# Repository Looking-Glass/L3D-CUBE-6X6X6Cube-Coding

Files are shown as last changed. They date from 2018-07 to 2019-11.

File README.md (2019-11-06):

# HOW TO PROGRAM THE 6X6X6 CUBE WITH ARDUINO

Step 1.     Followed the instructions in the Arduino_STM wiki: https://github.com/rogerclarkmelbourne/Arduino_STM32/wiki/Installation

Step 2. 	  Unzip <L3D_CubePixel.zip> and <beta-cube-library.zip> and put these two libraries under arduino library folder  ..\..\arduino-1.6.5-r5-windows\arduino-1.6.5-r5\libraries

Step 3.        Restart Arduino IDE, then select Maple (Rev3) for programming.
**If you can not find Maple(Rev3) on the board menu, replace the Arduino_STM32 folder with this one https://github.com/rogerclarkmelbourne/Arduino_STM32

**Enclosed two Demos x6CubeDemo.zip and x6CubeMusicPack.zip for reference, enjoy!

The Schematic and PCB source files can be open with Eagle PCB.

Enclosed some screenshot for Arauino IDE setting up for reference as well

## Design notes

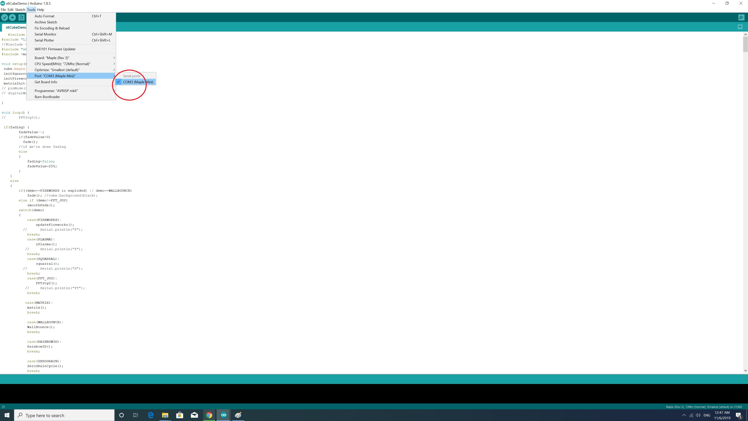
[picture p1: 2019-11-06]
select Maple for Port.jpg

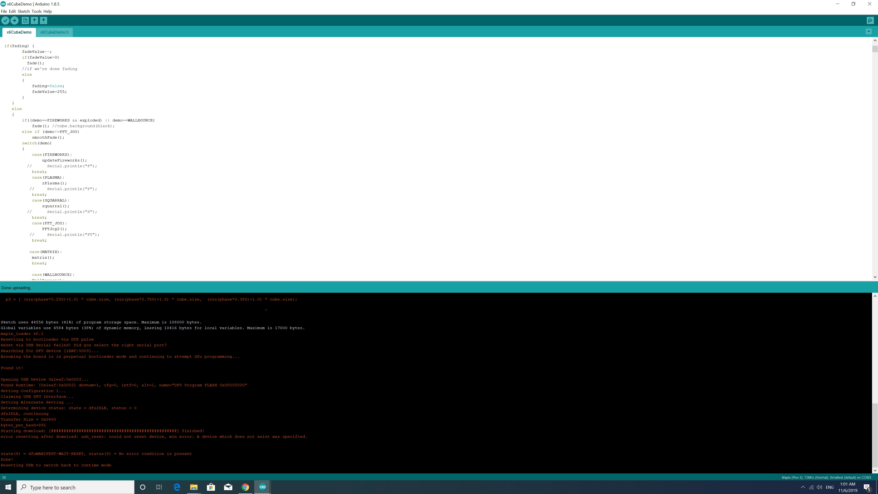
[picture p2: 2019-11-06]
done uploading.jpg

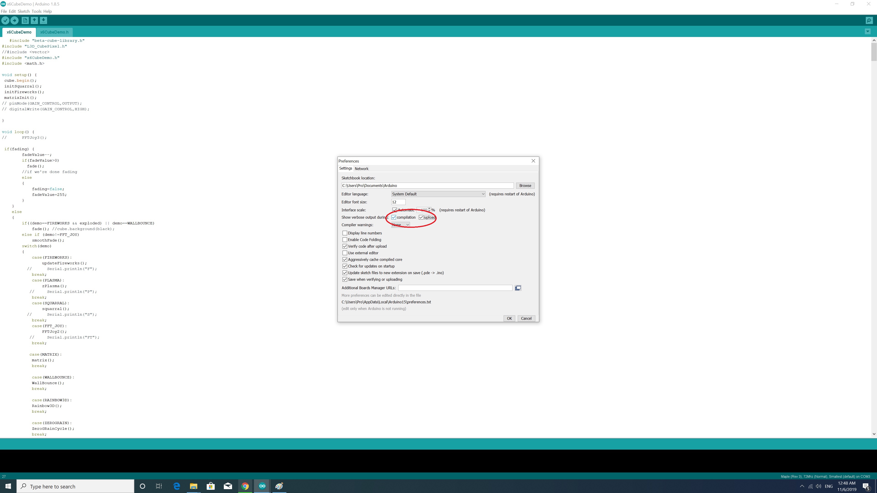
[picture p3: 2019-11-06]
enable verbose output during compilation and upload.jpg

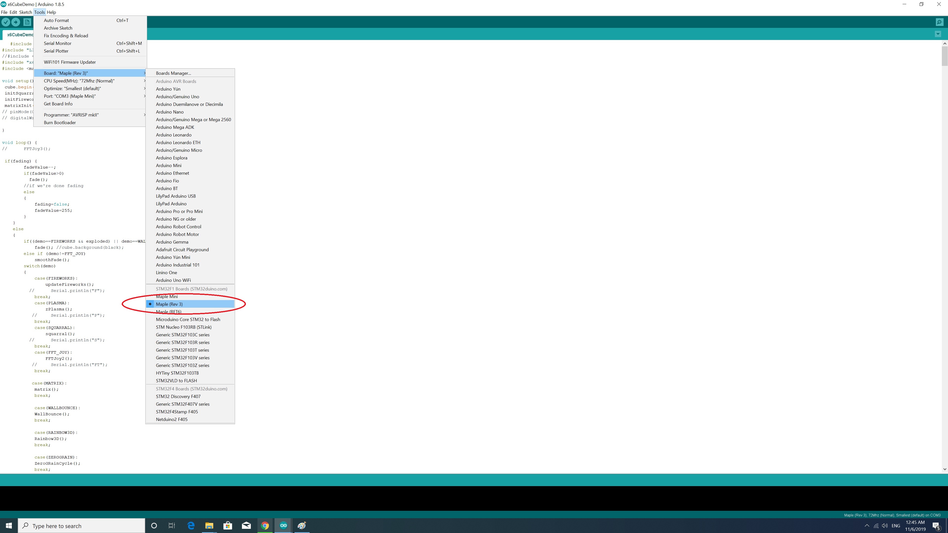
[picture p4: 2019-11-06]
select Maple (Rev3) for Board.jpg

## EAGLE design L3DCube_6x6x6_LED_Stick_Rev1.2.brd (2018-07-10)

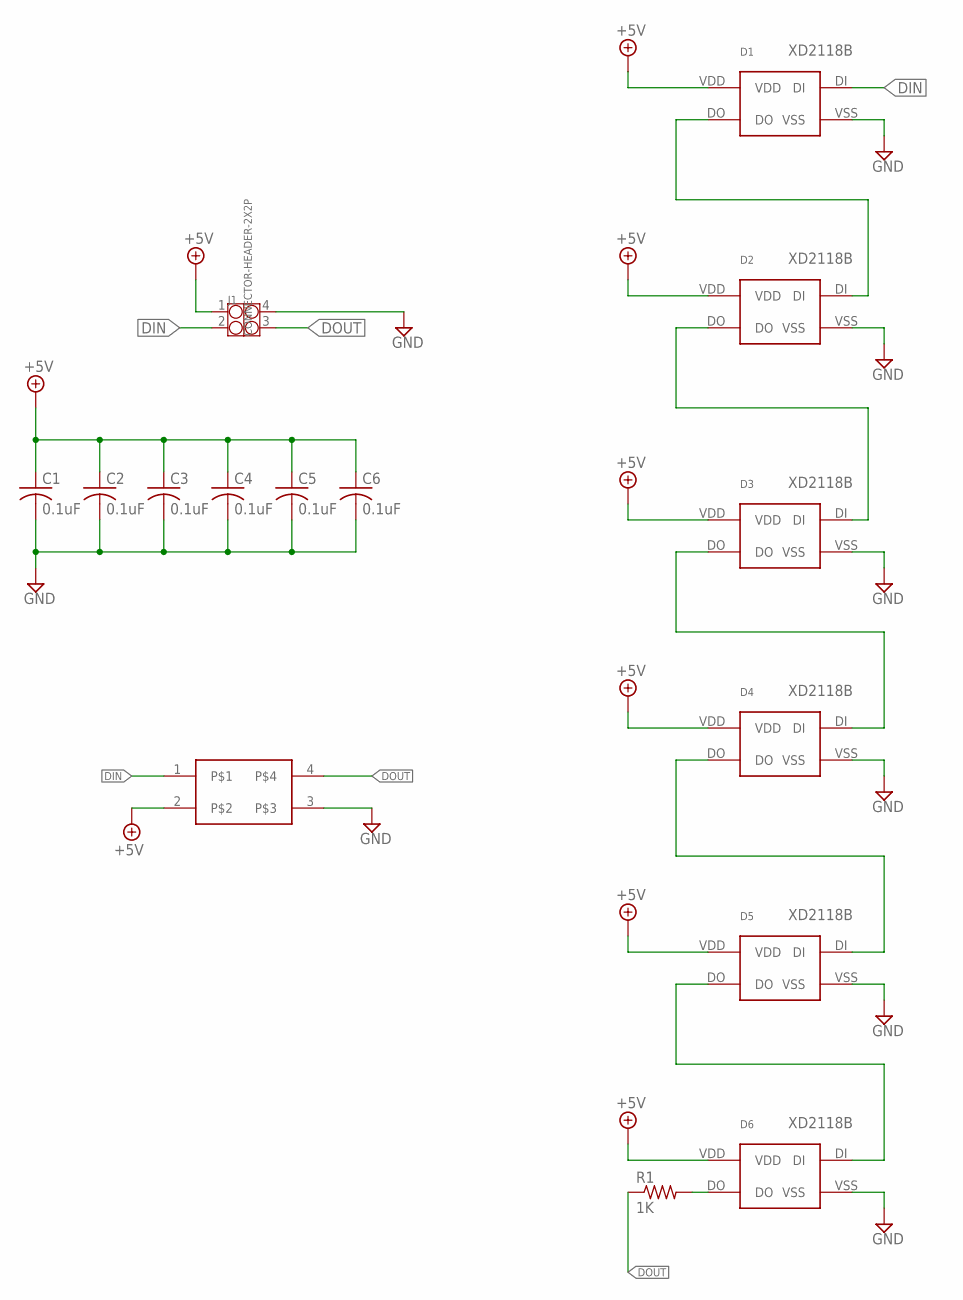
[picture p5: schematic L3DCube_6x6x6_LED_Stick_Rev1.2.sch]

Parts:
C1, C2, C3, C4, C5, C6: 0.1uF; C0402
D1, D2, D3, D4, D5, D6: XD2118B; WS2812B
J1: CONNECTOR-HEADER-2X2P; 2X2P-2.54
R1: 1K; R0402
U$1: TESTPAD-2X2-2.54; 2X2P-2.54-TESTPAD

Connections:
+5V: C1.1, C2.1, C3.1, C4.1, C5.1, C6.1, D1.VDD, D2.VDD, D3.VDD, D4.VDD, D5.VDD, D6.VDD, J1.1, U$1.2
DIN: D1.DI, J1.2, U$1.1
DOUT: J1.3, R1.1, U$1.4
GND: C1.2, C2.2, C3.2, C4.2, C5.2, C6.2, D1.VSS, D2.VSS, D3.VSS, D4.VSS, D5.VSS, D6.VSS, J1.4, U$1.3
unnamed: D1.DO, D2.DI
unnamed: D2.DO, D3.DI
unnamed: D3.DO, D4.DI
unnamed: D4.DO, D5.DI
unnamed: D5.DO, D6.DI
unnamed: D6.DO, R1.2

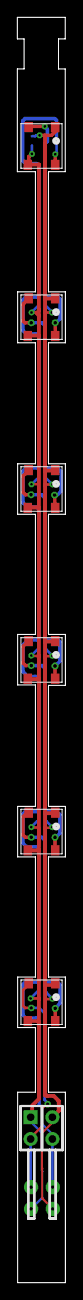
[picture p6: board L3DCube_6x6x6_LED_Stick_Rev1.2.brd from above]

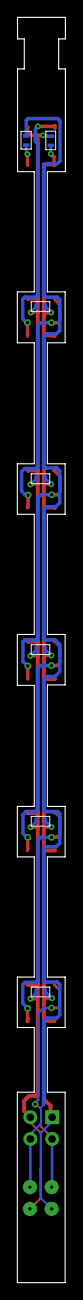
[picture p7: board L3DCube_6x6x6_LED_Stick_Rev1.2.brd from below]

Board: 2 copper layers, 5.6 x 147.6 mm, 15 parts (7 on the bottom side), 10 nets.

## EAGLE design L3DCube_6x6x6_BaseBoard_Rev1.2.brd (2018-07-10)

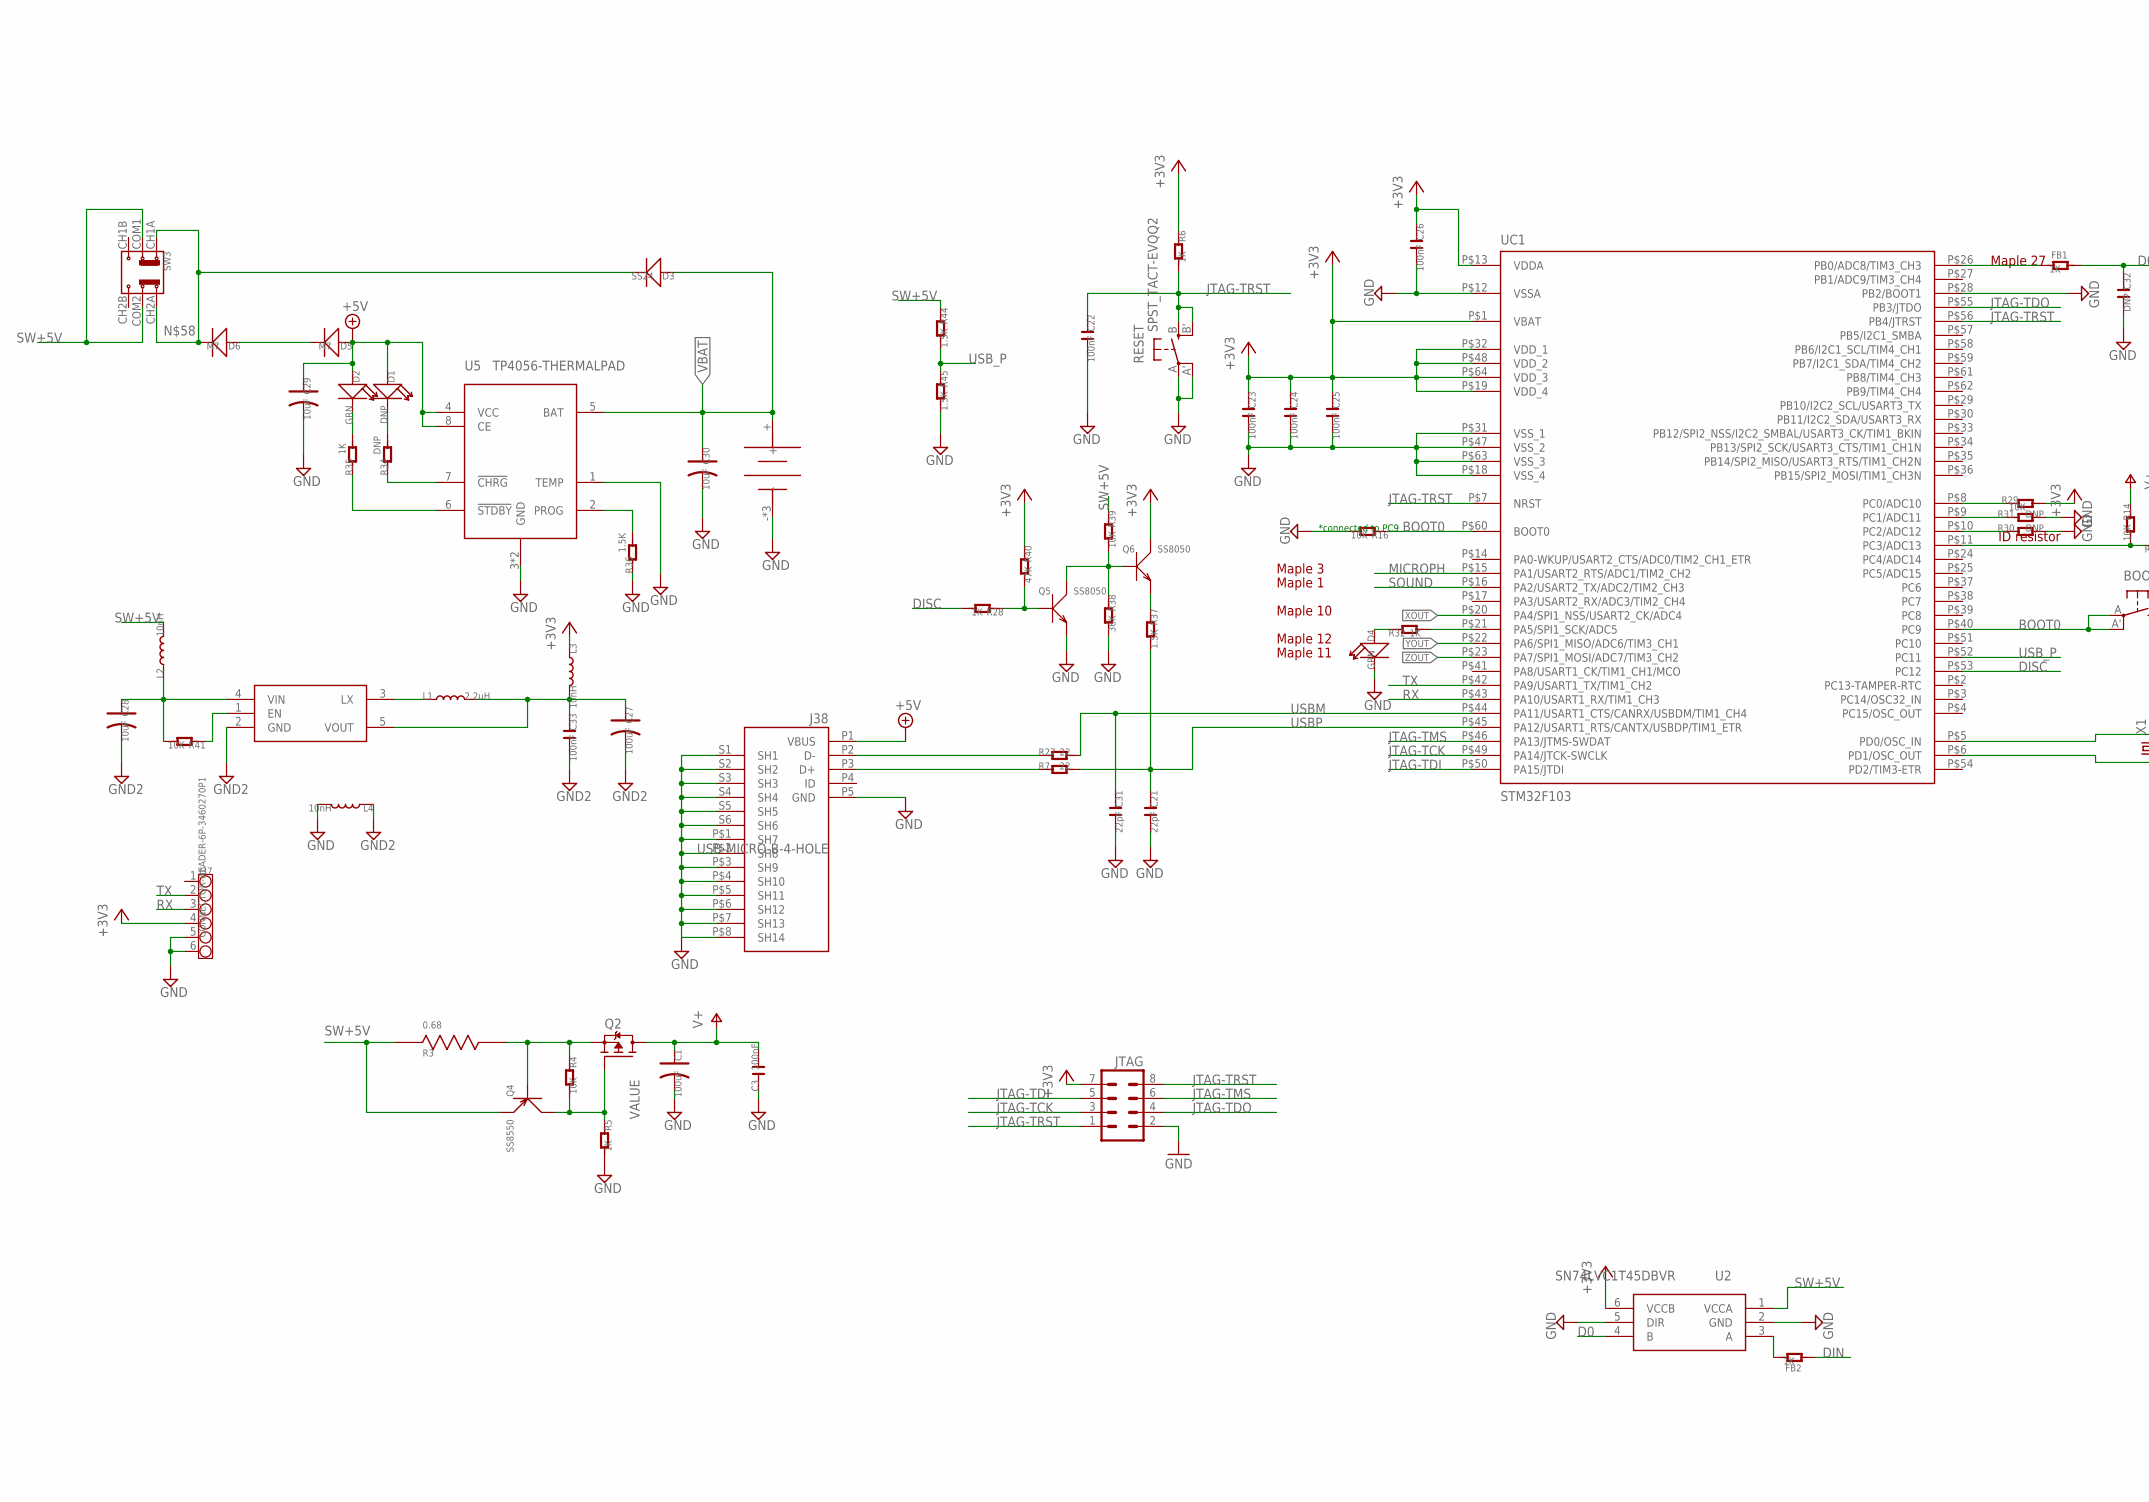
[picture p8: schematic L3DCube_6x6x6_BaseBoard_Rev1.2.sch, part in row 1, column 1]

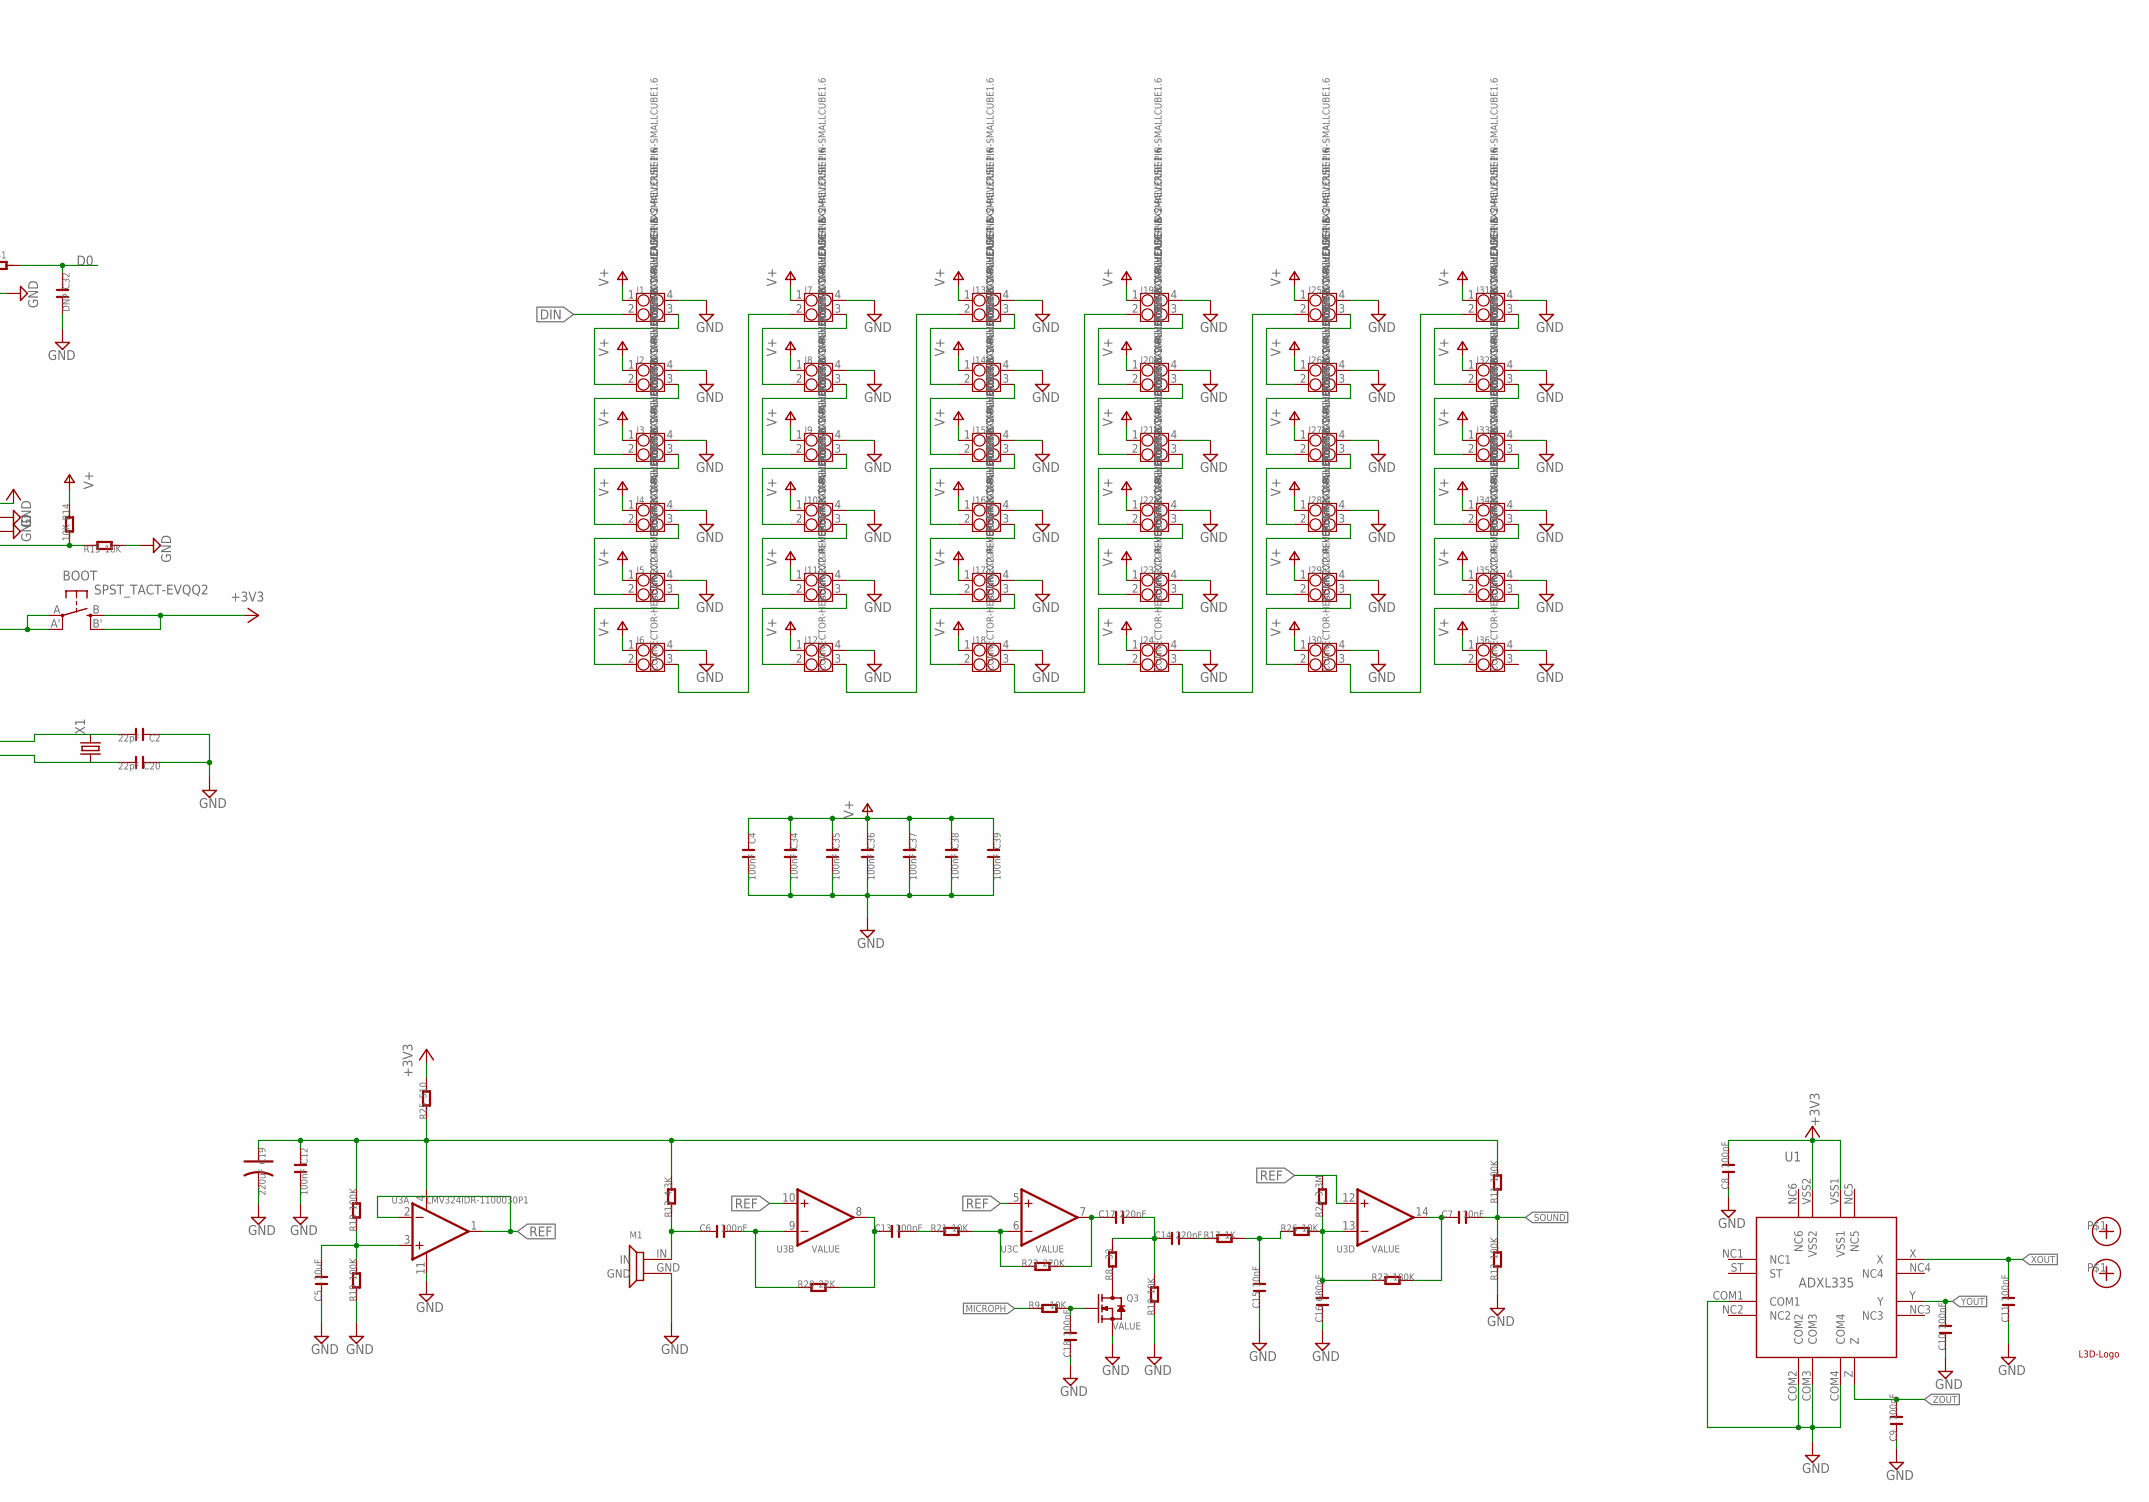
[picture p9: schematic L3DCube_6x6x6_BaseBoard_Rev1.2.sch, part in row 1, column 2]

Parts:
B1: BATTERY; 2P-SMD-2.0-90D
BOOT: SPST_TACT-EVQQ2; EVQ-Q2
C1, C27: 100uF; AVX-B
C2, C20, C21, C31: 22pF; C0603
C3, C4, C6, C8, C9, C10, C11, C12, C13, C18, C22, C23, C24, C25, C26, C33, C34, C35, C36, C37, C38, C39: 100nF; C0603
C5: 10uF; C0603
C7, C15: 10nF; C0603
C14, C17: 220nF; C0603
C16: 680pF; C0603
C19: 220uF; AVX-B
C28, C29, C30: 10uF; AVX-A
C32: DNP; C0603
D1: DNP; LED0603
D2, D4: GRN; LED0603
D3: SS24; SMB
D5, D6: M7; DO-214AC
FB1, FB2: 1K; R0603
J1, J2, J3, J4, J5, J6, J7, J8, J9, J10, J11, J12, J13, J14, J15, J16, J17, J18, J19, J20, J21, J22, J23, J24, J25, J26, J27, J28, J29, J30, J31, J32, J33, J34, J35, J36: CONNECTOR-HEADER-2X2-REVERSE-PIN-SMALLCUBE1.6; 2X2P-2.54-6X6X6-CUBE-TH
J37: CONNECTOR-HEADER-6P-3460270P1; 1X6P-2.54-8.5-BLACK-FEMALE
J38: USB-MICRO-B-4-HOLE; CON2_USB_MICRO_B_AT
JTAG: MA04-2
L1: 2.2uH; L0420
L2, L3, L4: 10nH; L0603
M1: MICROPHONE
Q2: FDD6637; TO252
Q3: 2N7002; SOT23
Q4: SS8550; SOT23
Q5, Q6: SS8050; SOT23
R3: 0.68; RESISTOR-3W-20MM
R4, R9, R10, R14, R15, R16, R21, R26, R29, R39: 10K; R0603
R5, R6, R17, R28, R32, R35: 1K; R0603
R7, R27: 22; R0603
R8: 33; R0603
R11, R12, R18, R19: 100K; R0603
R13: 4.3K; R0603
R20: 22K; R0603
R22: 220K; R0603
R23: 180K; R0603
R24: 3.3M; R0603
R25: 510; R0603
R30, R31, R34: DNP; R0603
R36, R37, R44, R45: 1.5K; R0603
R38: 36K; R0603
R40: 47K; R0603
R41: 10K; R0402
RESET: SPST_TACT-EVQQ2; EVQ-Q2
SW3: SWITCH-22D02
U1: ADXL335
U2: SN74LVC1T45DBVR; SOT23-6
U3: LMV324IDR-1100030P1; SOIC14
U5: TP4056-THERMALPAD; SOIC8-PAD
U11: R8008-33; SOT23-5
U$1: L3D-LOGOL3DCUBE-LOGO-0.8X2.5; L3DCUBE-LOGO-0.8X2.5
U$2, U$3: FIDUCIAL-MARK
UC1: STM32F103; TQFP-10X10-64
X1: CRYSTALSM49; SM49

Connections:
+3V3: BOOT.B (S), BOOT.B' (S1), C8.2, C23.1, C24.1, C25.1, C26.1, J37.4, JTAG.7, L3.1, Q6.3 (C), R6.1, R25.2, R29.1, R40.1, U1.VSS1, U1.VSS2, U2.6 (VCCB), UC1.P$1 (VBAT), UC1.P$13 (VDDA), UC1.P$19 (VDD_4), UC1.P$32 (VDD_1), UC1.P$48 (VDD_2), UC1.P$64 (VDD_3)
+5V: C29.+ (1), D1.+, D2.+, D5.1 (+), J38.P1 (VBUS), U5.4 (VCC), U5.8 (CE)
BOOT0: BOOT.A, BOOT.A' (P1), R16.1, UC1.P$40 (PC9), UC1.P$60 (BOOT0)
D0: C32.1, FB1.1, U2.4 (B)
DIN: FB2.1, J1.2
DISC: R28.2, UC1.P$53 (PC12)
ENABLE: R41.1, U11.1 (EN)
GND: B1.3 (-), B1.4 (-), B1.-, C1.- (2), C2.1, C3.1, C4.2, C5.1, C8.1, C9.1, C10.1, C11.1, C12.2, C15.1, C16.1, C18.1, C19.- (2), C20.1, C21.2, C22.2, C23.2, C24.2, C25.2, C26.2, C29.- (2), C30.- (2), C31.2, C32.2, C34.2, C35.2, C36.2, C37.2, C38.2, C39.2, D4.-, J1.4, J2.4, J3.4, J4.4, J5.4, J6.4, J7.4, J8.4, J9.4, J10.4, J11.4, J12.4, J13.4, J14.4, J15.4, J16.4, J17.4, J18.4, J19.4, J20.4, J21.4, J22.4, J23.4, J24.4, J25.4, J26.4, J27.4, J28.4, J29.4, J30.4, J31.4, J32.4, J33.4, J34.4, J35.4, J36.4, J37.5, J37.6, J38.P5 (GND), J38.P$1 (SH7), J38.P$2 (SH8), J38.P$3 (SH9), J38.P$4 (SH10), J38.P$5 (SH11), J38.P$6 (SH12), J38.P$7 (SH13), J38.P$8 (SH14), J38.S1 (SH1), J38.S2 (SH2), J38.S3 (SH3), J38.S4 (SH4), J38.S5 (SH5), J38.S6 (SH6), JTAG.2, L4.2, M1.GND, Q3.2 (S), Q5.2 (E), R5.2, R10.1, R12.1, R15.2, R16.2, R19.1, R30.2, R31.2, R36.1, R38.2, R45.2, RESET.A, RESET.A' (P1), U1.COM1, U1.COM2, U1.COM3, U1.COM4, U2.2 (GND), U2.5 (DIR), U3.11 (V-), U5.1 (TEMP), U5.3 (GND), U5.GND1 (GND), UC1.P$12 (VSSA), UC1.P$18 (VSS_4), UC1.P$28 (PB2/BOOT1), UC1.P$31 (VSS_1), UC1.P$47 (VSS_2), UC1.P$63 (VSS_3)
GND2: C27.- (2), C28.- (2), C33.2, L4.1, U11.2 (GND)
JTAG-TCK: JTAG.3, UC1.P$49 (PA14/JTCK-SWCLK)
JTAG-TDI: JTAG.5, UC1.P$50 (PA15/JTDI)
JTAG-TDO: JTAG.4, UC1.P$55 (PB3/JTDO)
JTAG-TMS: JTAG.6, UC1.P$46 (PA13/JTMS-SWDAT)
JTAG-TRST: C22.1, JTAG.1, JTAG.8, R6.2, RESET.B (S), RESET.B' (S1), UC1.P$7 (NRST), UC1.P$56 (PB4/JTRST)
LED1: D4.+, R32.1
MICROPH: R9.1, UC1.P$15 (PA1/USART2_RTS/ADC1/TIM2_CH2)
unnamed: J1.3, J2.2
unnamed: J2.3, J3.2
unnamed: J3.3, J4.2
unnamed: J4.3, J5.2
unnamed: J5.3, J6.2
unnamed: J7.3, J8.2
unnamed: J8.3, J9.2
unnamed: J9.3, J10.2
unnamed: J10.3, J11.2
unnamed: J11.3, J12.2
unnamed: J13.3, J14.2
unnamed: J14.3, J15.2
unnamed: J15.3, J16.2
unnamed: J16.3, J17.2
unnamed: J17.3, J18.2
unnamed: J19.3, J20.2
unnamed: J20.3, J21.2
unnamed: J21.3, J22.2
unnamed: J22.3, J23.2
unnamed: J23.3, J24.2
unnamed: J25.3, J26.2
unnamed: J26.3, J27.2
unnamed: J27.3, J28.2
unnamed: J28.3, J29.2
unnamed: J29.3, J30.2
unnamed: J31.3, J32.2
unnamed: J32.3, J33.2
unnamed: J33.3, J34.2
unnamed: J34.3, J35.2
unnamed: J35.3, J36.2
unnamed: J6.3, J7.2
unnamed: C18.2, Q3.1 (G), R9.2
unnamed: J12.3, J13.2
unnamed: J18.3, J19.2
unnamed: J24.3, J25.2
unnamed: J30.3, J31.2
unnamed: C2.2, UC1.P$5 (PD0/OSC_IN), X1.2
unnamed: C20.2, UC1.P$6 (PD1/OSC_OUT), X1.1
unnamed: R14.2, R15.1, UC1.P$11 (PC3/ADC13)
unnamed: J38.P2 (D-), R27.1
unnamed: L1.1, U11.3 (LX)
unnamed: D1.-, R34.2
unnamed: R32.2, UC1.P$21 (PA5/SPI1_SCK/ADC5)
unnamed: FB1.2, UC1.P$26 (PB0/ADC8/TIM3_CH3)
unnamed: R29.2, UC1.P$8 (PC0/ADC10)
unnamed: D2.-, R35.2
unnamed: R34.1, U5.7 (!CHRG)
unnamed: R35.1, U5.6 (!STDBY)
unnamed: R36.2, U5.2 (PROG)
unnamed: R30.1, UC1.P$10 (PC2/ADC12)
unnamed: Q6.2 (E), R37.1
unnamed: C28.+ (1), L2.1, R41.2, U11.4 (VIN)
unnamed: R31.1, UC1.P$9 (PC1/ADC11)
unnamed: J38.P3 (D+), R7.1
unnamed: C27.+ (1), C33.1, L1.2, L3.2, U11.5 (VOUT)
unnamed: FB2.2, U2.3 (A)
unnamed: D3.-, D6.2 (-), SW3.CH1A, SW3.CH2A
unnamed: D5.2 (-), D6.1 (+)
unnamed: Q2.2 (S), Q4.1 (B), R3.2, R4.1
unnamed: Q3.3 (D), R8.1
unnamed: Q2.1 (G), Q4.3 (C), R4.2, R5.1
unnamed: C14.2, R17.1
unnamed: C15.2, R17.2, R26.1
unnamed: C16.2, R23.1, R24.1, R26.2, U3.13 (IN-)
unnamed: Q5.3 (C), Q6.1 (B), R38.1, R39.2
unnamed: C6.1, M1.IN, R13.1
unnamed: Q5.1 (B), R28.1, R40.2
unnamed: C5.2, R18.1, R19.2, U3.3 (IN+)
unnamed: C6.2, R20.1, U3.9 (IN-)
unnamed: C13.1, R20.2, U3.8 (OUT)
unnamed: C13.2, R21.1
unnamed: R21.2, R22.1, U3.6 (IN-)
unnamed: C14.1, C17.2, R8.2, R10.2
unnamed: C12.1, C19.+ (1), R11.2, R13.2, R18.2, R25.1, U3.4 (V+)
unnamed: C7.1, R23.2, U3.14 (OUT)
unnamed: C17.1, R22.2, U3.7 (OUT)
REF: R24.2, U3.1 (OUT), U3.2 (IN-), U3.5 (IN+), U3.10 (IN+), U3.12 (IN+)
RX: J37.3, UC1.P$43 (PA10/USART1_RX/TIM1_CH3)
SOUND: C7.2, R11.1, R12.2, UC1.P$16 (PA2/USART2_TX/ADC2/TIM2_CH3)
SW+5V: L2.2, Q4.2 (E), R3.1, R39.1, R44.1, SW3.COM1, SW3.COM2, U2.1 (VCCA)
TX: J37.2, UC1.P$42 (PA9/USART1_TX/TIM1_CH2)
USBM: C31.1, R27.2, UC1.P$44 (PA11/USART1_CTS/CANRX/USBDM/TIM1_CH4)
USBP: C21.1, R7.2, R37.2, UC1.P$45 (PA12/USART1_RTS/CANTX/USBDP/TIM1_ETR)
USB_P: R44.2, R45.1, UC1.P$52 (PC11)
V+: C1.+ (1), C3.2, C4.1, C34.1, C35.1, C36.1, C37.1, C38.1, C39.1, J1.1, J2.1, J3.1, J4.1, J5.1, J6.1, J7.1, J8.1, J9.1, J10.1, J11.1, J12.1, J13.1, J14.1, J15.1, J16.1, J17.1, J18.1, J19.1, J20.1, J21.1, J22.1, J23.1, J24.1, J25.1, J26.1, J27.1, J28.1, J29.1, J30.1, J31.1, J32.1, J33.1, J34.1, J35.1, J36.1, Q2.3 (D), R14.1
VBAT: B1.+, C30.+ (1), D3.+, U5.5 (BAT)
XOUT: C11.2, U1.X, UC1.P$20 (PA4/SPI1_NSS/USART2_CK/ADC4)
YOUT: C10.2, U1.Y, UC1.P$22 (PA6/SPI1_MISO/ADC6/TIM3_CH1)
ZOUT: C9.2, U1.Z, UC1.P$23 (PA7/SPI1_MOSI/ADC7/TIM3_CH2)

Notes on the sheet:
*connected to PC9
ID resistor
Maple 27
Maple 3
Maple 1
Maple 10
Maple 12
Maple 11

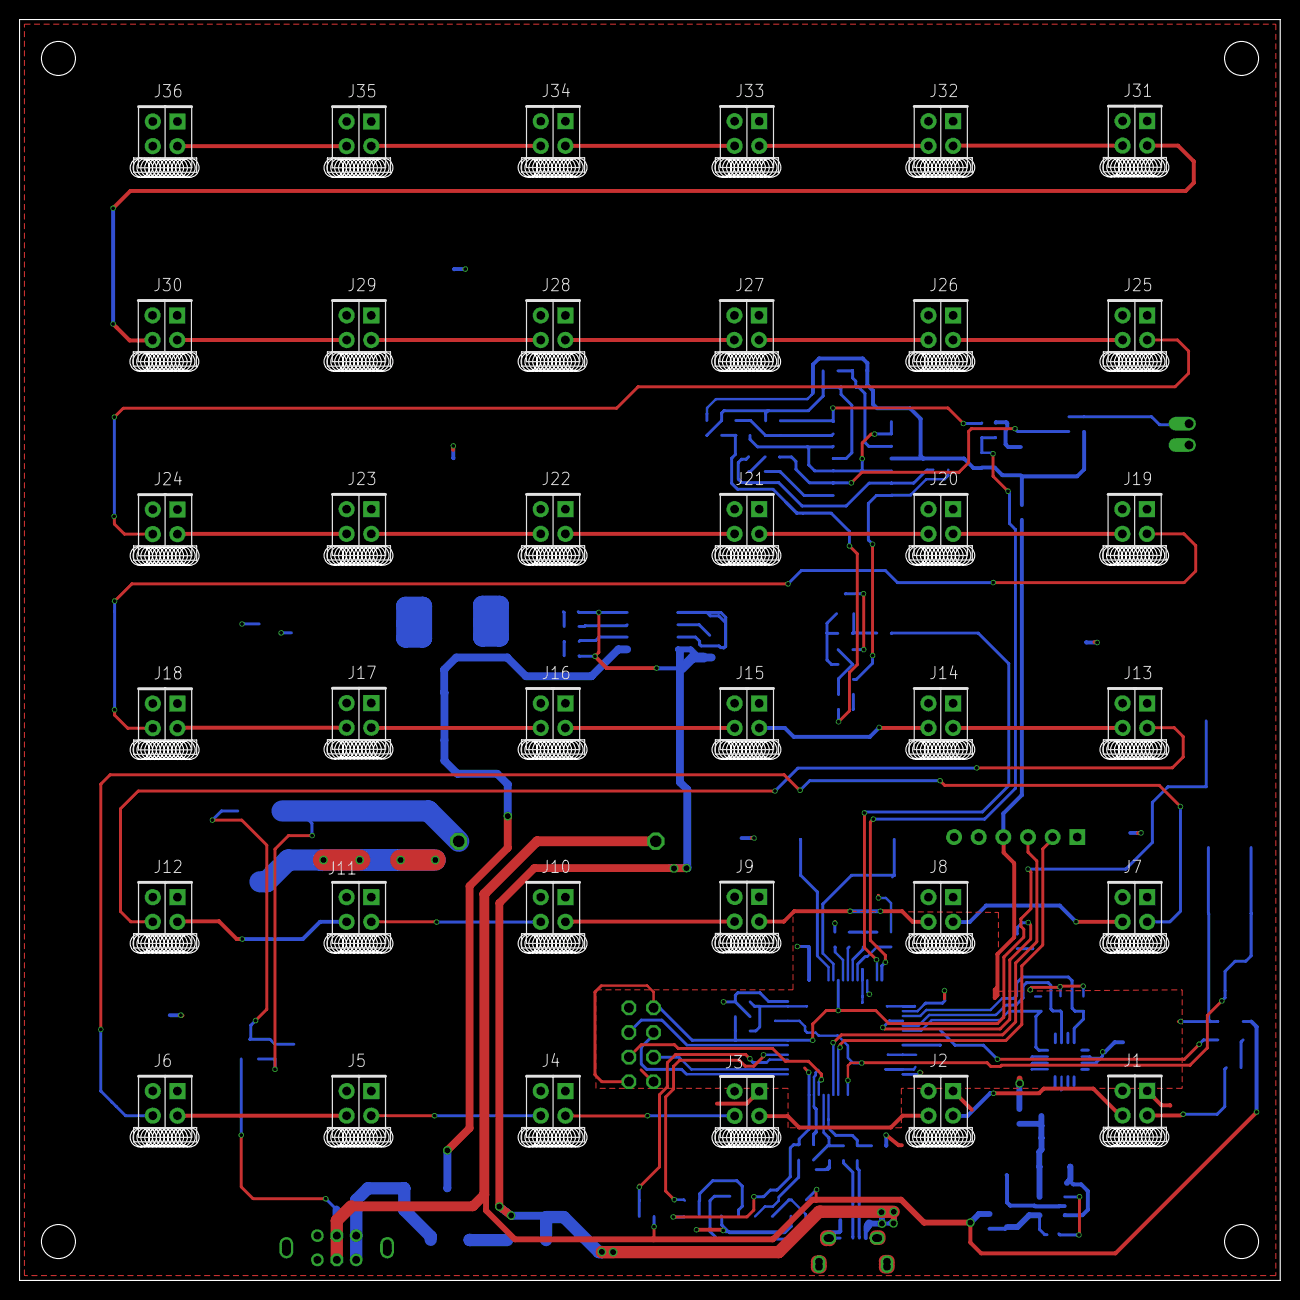
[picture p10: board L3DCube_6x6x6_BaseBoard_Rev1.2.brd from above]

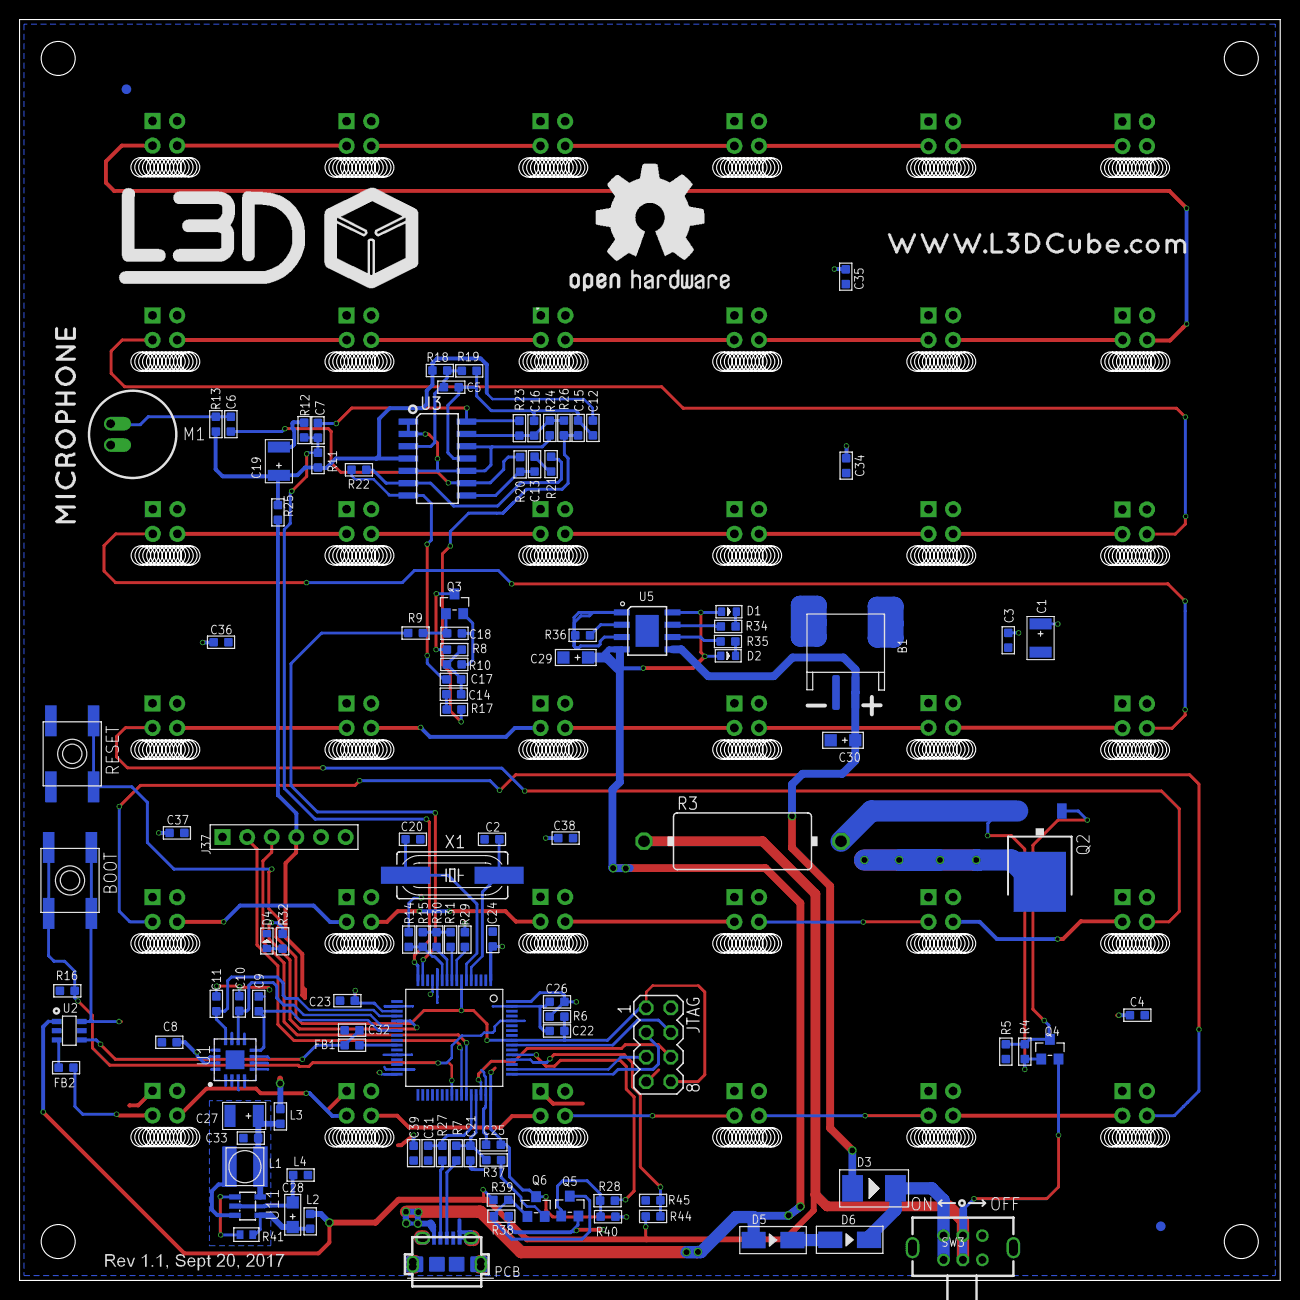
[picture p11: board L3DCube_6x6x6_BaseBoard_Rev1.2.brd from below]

Board: 2 copper layers, 130.0 x 130.0 mm, 150 parts (114 on the bottom side), 105 nets.
